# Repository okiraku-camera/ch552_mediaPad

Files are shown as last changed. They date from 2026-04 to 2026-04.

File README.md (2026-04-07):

# CH552 MediaPad

English version: [README_en.md](README_en.md)

CH552G マイクロコントローラを使ったUSB HID マクロパッド（2x4キー + エンコーダ搭載）です。WebHID を使ってキーマップをリアルタイムで設定・変更できます。

## フォルダ構成

- **`pcb/`**: KiCAD 8 による基板設計（回路図、PCB）
- **`plates/`**: レーザーカット用アクリルプレート設計
- **`mediaPad/`**: Arduino ファームウェア（CH552G 向け）
- **`html/`**: WebHID 設定用ブラウザアプリ（HTML/CSS/JavaScript）
- **`LICENSE`**: プロジェクトライセンス

## ハードウェア

- **マイコン**: CH552G
- **キー**: 8キー（2x4 レイアウト）
- **エンコーダ**: 1個
- **トッププレート**: 5mm アクリル（透明）
- **ミドルプレート**: 5mm アクリル（マット透明）
- **ボトムプレート**: 2mm アクリル（透明）
- **USB**: USB Type-C コネクタ

詳細は [pcb/README.md](pcb/README.md)・[plates/README.md](plates/README.md) をご覧ください。

## ソフトウェア

### ファームウェア (mediaPad/)
CH552G 向けの Arduino スケッチ。USB HID キーボード・メディア操作・エンコーダ入力に対応しています。

### Web アプリ (html/)
ブラウザから **WebHID** 経由でデバイスと通信し、キーマップの読み書きや設定変更ができるアプリケーションです。(ch552_mediaPad.html)

## ライセンス

このプロジェクトはハードウェアとソフトウェアから構成されています。

Copyright (c) Takeshi Higasa, okiraku-camera.tokyo

詳細は [LICENSE](./LICENSE) をご覧ください。

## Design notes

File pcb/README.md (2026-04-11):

# PCB (ch552_mediaPad)

このディレクトリには、CH552 MediaPad の KiCad 設計データ（回路図・基板レイアウト）が含まれています。

## 使用ツール

- KiCad 8.0

## 含まれる主なファイル

- `ch552_mediaPad.kicad_sch` : 回路図
- `ch552_mediaPad.kicad_pcb` : PCB レイアウト
- `ch552_mediaPad.kicad_pro` : プロジェクト設定
- `local/` : この PCB のためのフットプリントライブラリ

### local/ ディレクトリの内容

- `Hole_M3_SmallPad.kicad_mod` : M3 取り付け穴
- `MX_PCB_1.25u.kicad_mod` : 1.25u キースイッチ用フットプリント
- `MX_Plate_hole.kicad_mod` : MX スイッチ用フットプリントと置き換えて、スイッチプレートを設計するためのフットプリント
- `SW_Cherry_MX_PCB_RE_1.25u.kicad_mod` : MX 1.25U とロータリーエンコーダー EC-12 を組み合わせたフットプリント
- `USB_C_Receptacle_304J-BCP16.kicad_mod` : USB Type-C コネクタ

## メモ

- 共同作業時は、編集対象（回路図/PCB）と合わせて関連設定ファイルの差分も確認してください。

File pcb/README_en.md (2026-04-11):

# PCB (ch552_mediaPad)

This directory contains KiCad design data (schematics and PCB layout) for CH552 MediaPad.

## Tool

- KiCad 8.0

## Main Files

- `ch552_mediaPad.kicad_sch` : Schematic
- `ch552_mediaPad.kicad_pcb` : PCB layout
- `ch552_mediaPad.kicad_pro` : Project settings
- `local/` : Footprint library for this PCB

### Contents of local/

- `Hole_M3_SmallPad.kicad_mod` : M3 mounting hole
- `MX_PCB_1.25u.kicad_mod` : Footprint for 1.25u MX switch
- `MX_Plate_hole.kicad_mod` : Footprint used to design a switch plate by replacing the MX switch footprint
- `SW_Cherry_MX_PCB_RE_1.25u.kicad_mod` : Combined footprint for MX 1.25U and rotary encoder EC-12
- `USB_C_Receptacle_304J-BCP16.kicad_mod` : USB Type-C connector

## Notes

- When collaborating, check diffs in related project setting files along with schematic/PCB edits.

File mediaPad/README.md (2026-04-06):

# mediaPad firmware

English version is here: [README_en.md](README_en.md)

このディレクトリには、mediaPad ファームウェア（Arduino スケッチ）が入っています。

## 概要

mediaPad は、CH552G を使った **プログラマブルなメディアパッド/マクロパッド** です。  
キースキャン、ロータリーエンコーダ入力、USB HID 送信、キーマップ/マクロの永続保存を行い、WebHID ベースの WebUI から設定を変更できます。

このファームウェアの対象ハードウェアは **ch552_mediaPad** です。

## 主な機能

- **8 キー + ロータリーエンコーダ入力**: 2x4 のキー入力とエンコーダ回転を処理
- **2 レイヤーキーマップ**: EEPROM 上の 2 層キーマップを切り替えて利用
- **エンコーダ割り当て**: レイヤーごとに CW / CCW のキーコードを設定可能
- **マクロ機能**: 最大 6 個のマクロを保存し、割り当てキーから順次送信
- **WebUI 設定**: WebHID 経由でキーマップ、エンコーダ、マクロをブラウザから編集可能
- **永続ストレージ**: 設定は NVM（内蔵 EEPROM）に保存

## ソフトウェア構成

### ハードウェア層
| ファイル | 役割 |
|---|---|
| `mediaPad.ino` | メインスケッチ。入力スキャン、キー送信、レイヤー/マクロ制御 |
| `r_encoder.c/.h` | ロータリーエンコーダ入力処理 |
| `serial_led.c/.h` | LED 表示制御 |

### レイヤー・キーマップ管理
| ファイル | 役割 |
|---|---|
| `nvm_keymap.c/.h` | EEPROM へのキーマップ/マクロ保存処理 |
| `hardware_config.h` | キー数、レイヤー数、EEPROM マップなどの定数定義 |

### USB HID 通信
| ファイル | 役割 |
|---|---|
| `USB_hid_composite.c/.h` | USB HID 複合デバイス実装 |
| `hid_raw_request.c` | WebHID 設定要求（読み書きコマンド）処理 |

### PC側 Web アプリケーション
| ファイル | 役割 |
|---|---|
| `html/ch552_mediaPad.html` | Web アプリケーション画面 |
| `html/ch552_mediaPad.js` | WebHID 通信と UI ロジック |
| `html/style.css` | スタイル定義 |

## 動作モード

### レイヤー切り替え
- 2 レイヤーのキーマップを持ちます
- SW7 は固定 Fn キーとして扱われ、通常のキー割り当て変更対象ではありません
- Fn 操作により現在レイヤーを切り替えます

### エンコーダ動作
- ロータリーエンコーダ 1 個を搭載した構成です
- レイヤーごとに CW / CCW の 2 方向へ別々のキーコードを割り当てられます
- 既定ではメディア操作やスクロール系コードを割り当てる運用を想定しています

### マクロ動作
- マクロキー押下で登録済みマクロを順次送信します
- 実行中に別のキー入力があると、送信中マクロは停止します
- 遅延コードと繰返し制御コードを含むマクロを実行できます

## 使い方

### クイックスタート
1. ブラウザで `html/ch552_mediaPad.html` を開きます。
2. 「キーボードに接続」を押してデバイスを選択します。
3. 必要に応じてキーマップ、エンコーダ割り当て、マクロを編集します。
4. 「キーマップを書き込む」「マクロを書き込む」でデバイスへ保存します。

### WebUI の詳細手順

WebUI の操作手順は、以下の分離ドキュメントにまとめています。

- 日本語: `html/README.md`
- English: `html/README_en.md`

## ビルド方法

このファームウェアのビルドには、以下のソフトウェアが必要です。

- Visual Studio Code + vscode-arduino 拡張
- arduino-cli
- CH55xDuino
- Arduino libraries 配下の `ch552_keyPad_Library` が必須。

### arduino.json によるデバイス切り分け

本プロジェクトでは、デバイスごとのビルド依存設定を各スケッチディレクトリの `.vscode/arduino.json` で分離しています。

- `macro_numpad/.vscode/arduino.json`:
	- `sketch`: `macro_numpad.ino`
	- `buildPreferences`: `-DBOARD_NAME=CH552_MACRO_NUMPAD -I../common`
- `mediaPad/.vscode/arduino.json`:
	- `sketch`: `mediaPad.ino`
	- `buildPreferences`: `-DBOARD_NAME=CH552_MEDIAPAD -I../common`

この構成により、`software/common` の共通モジュールを再利用しながら、ターゲットごとのハードウェア依存データをボード名を使ったマクロで切り分けています。`.vscode/arduino.json` は以下のようになっています。

```json
{
    "configuration": "clock=16internal,usb_settings=user148,upload_method=usb,bootloader_pin=p36",
    "board": "CH55xDuino:mcs51:ch552",
    "sketch": "mediaPad\\mediaPad.ino",
    "output": "./built",
    "port": "COM1",
    "buildPreferences": [
        ["compiler.cpp.extra_flags","-DCH552_MEDIAPAD"],
        ["compiler.c.extra_flags","-DCH552_MEDIAPAD"]
    ]
}
```

VS Code の vscode-arduino 拡張は内部で arduino-cli を利用し、これらの設定を使ってビルドします。

### ボード設定

ボード設定メニューで以下を選択してください。

- USB Settings: `USER CODE w/ 148B USB ram`

この設定は HID エンドポイントに必要な USB RAM を確保するために必要です。

## 技術詳細

### NVM（128バイト）の使用方法
- **0～1バイト**: キーマップ有効フラグ（`0xAA55`）
- **2～33バイト**: 2 レイヤー分のキーキーマップ（8 キー x 2 バイト x 2 レイヤー）
- **34～41バイト**: ロータリーエンコーダ割り当て（1 個 x CW/CCW x 2 レイヤー x 2 バイト）
- **42～126バイト**: マクロ文字列データ
- **127バイト**: マクロ領域終端（予約）

### マクロ機能
- **最大 6 マクロ** を登録可能
- **マクロ領域は 85 バイト** です
- 1 マクロストリングの UI 上限は **50 バイト** です
- 各マクロはゼロ終端の連続列として管理されます

### マクロ制御コード
- **遅延コード**:
	- `0xDC` = 100ms
	- `0xDD` = 500ms
	- `0xDE` = 1sec
- **繰返しコード**:
	- `0xDA` = SEGSTART
	- `0xDB` = GOTO_SEG

### 繰返し動作の仕様
- `GOTO_SEG` は、そのマクロ内で最初に見つかった `SEGSTART` 位置へ戻ります
- `SEGSTART` が存在しない場合は、マクロ先頭へ戻ります

## トラブルシューティング

### デバイスが接続できない
- ブラウザが WebHID をサポートしているか確認してください（Chrome、Edge 推奨）
- デバイスが WebHID 通信可能な状態で接続されているか確認してください
- ブラウザの USB アクセス権限を確認してください

### キーマップやエンコーダ設定が反映されない
- 「キーマップを書き込む」で変更を保存しているか確認してください
- Pending 状態の変更は、読み出しだけでは反映されません
- 一度「キーマップを読み出す」を実行してから再編集すると切り分けしやすくなります

### マクロが期待どおり動作しない
- マクロスロットと割り当て先キーが正しいか確認してください
- マクロ容量上限を超えていないか確認してください
- 遅延コードや繰返しコードを意図どおりに配置しているか確認してください

## 補足

- Web 設定ツールは [html/ch552_mediaPad.html](html/ch552_mediaPad.html) を使用します
- 接続時にデバイスのバージョン番号を確認しています（想定値: `0x1234`）
- ブートローダー開始後はデバイスが一時的に切断されることがあります

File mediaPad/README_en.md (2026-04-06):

# mediaPad firmware

Japanese version is here: [README.md](README.md)

This directory contains the mediaPad firmware (Arduino sketch) for CH552G.

## Overview

mediaPad is a **programmable media pad / macro pad** based on CH552G.  
It handles key scanning, rotary encoder input, USB HID transmission, and persistent storage of keymaps/macros, and its settings can be updated from a WebHID-based Web UI.

The target hardware for this firmware is **ch552_mediaPad**.

## Main Features

- **8 keys + rotary encoder input**: handles a 2x4 key matrix and encoder rotation
- **2-layer keymap**: uses a two-layer keymap stored in EEPROM
- **Encoder assignment**: CW / CCW keycodes can be configured per layer
- **Macro support**: stores up to 6 macros and sends them from assigned keys
- **WebUI configuration**: keymaps, encoder assignments, and macros can be edited from the browser via WebHID
- **Persistent storage**: settings are stored in NVM (built-in EEPROM)

## Software Structure

### Hardware Layer
| File | Role |
|---|---|
| `mediaPad.ino` | Main sketch: input scan, key send, layer/macro control |
| `r_encoder.c/.h` | Rotary encoder input processing |
| `serial_led.c/.h` | LED control |

### Layer and Keymap Management
| File | Role |
|---|---|
| `nvm_keymap.c/.h` | EEPROM keymap/macro storage processing |
| `hardware_config.h` | Constants such as key count, layer count, and EEPROM layout |

### USB HID Communication
| File | Role |
|---|---|
| `USB_hid_composite.c/.h` | USB HID composite device implementation |
| `hid_raw_request.c` | WebHID configuration request handling (read/write commands) |

### PC-side Web Application
| File | Role |
|---|---|
| `html/ch552_mediaPad.html` | Web application UI |
| `html/ch552_mediaPad.js` | WebHID communication and UI logic |
| `html/style.css` | Styling |

## Operation Modes

### Layer Switching
- The firmware uses a 2-layer keymap
- SW7 is treated as a fixed Fn key and is not a normal remappable key
- Fn operation switches the current layer

### Encoder Behavior
- The device uses one rotary encoder
- Separate keycodes can be assigned to CW and CCW for each layer
- The default use case assumes media-control or scroll-related keycodes

### Macro Behavior
- Pressing a macro key sends the registered macro sequence
- If another key is pressed during macro execution, the running macro stops
- Macros can include delay codes and loop-control codes

## Usage

### Quick Start
1. Open `html/ch552_mediaPad.html` in a browser.
2. Click "Connect to Keyboard" and select the device.
3. Edit the keymap, encoder assignments, and macros as needed.
4. Save changes to the device with "Write keymap" and "Write macro".

### Detailed WebUI Guide

Detailed WebUI steps are documented in the following files.

- Japanese: `html/README.md`
- English: `html/README_en.md`

## Build

The following software is required to build this firmware.

- Visual Studio Code + vscode-arduino extension
- arduino-cli
- CH55xDuino
- `ch552_keyPad_Library` under Arduino libraries is required.

### Device Split by arduino.json

This project separates device-specific build settings using `.vscode/arduino.json` under each sketch directory.

- `macro_numpad/.vscode/arduino.json`:
	- `sketch`: `macro_numpad.ino`
	- `buildPreferences`: `-DBOARD_NAME=CH552_MACRO_NUMPAD -I../common`
- `mediaPad/.vscode/arduino.json`:
	- `sketch`: `mediaPad.ino`
	- `buildPreferences`: `-DBOARD_NAME=CH552_MEDIAPAD -I../common`

With this setup, shared modules in `software/common` are reused while hardware-dependent data is separated by the `BOARD_NAME` macro. See the `.vscode/arduino.json` files in the source tree for the concrete settings.

The `.vscode/arduino.json` file looks like this:

```json
{
	"configuration": "clock=16internal,usb_settings=user148,upload_method=usb,bootloader_pin=p36",
	"board": "CH55xDuino:mcs51:ch552",
	"sketch": "mediaPad\\mediaPad.ino",
	"output": "./built",
	"port": "COM1",
	"buildPreferences": [
		["compiler.cpp.extra_flags","-DCH552_MEDIAPAD"],
		["compiler.c.extra_flags","-DCH552_MEDIAPAD"]
	]
}
```

The vscode-arduino extension uses arduino-cli internally and builds with these settings.

### Board Settings

Select the following option in board settings.

- USB Settings: `USER CODE w/ 148B USB ram`

This setting is required to allocate the USB RAM needed for HID endpoints.

## Technical Details

### NVM layout (128 bytes)
- **Bytes 0-1**: keymap valid flag (`0xAA55`)
- **Bytes 2-33**: key keymap for 2 layers (8 keys x 2 bytes x 2 layers)
- **Bytes 34-41**: rotary encoder assignments (1 encoder x CW/CCW x 2 layers x 2 bytes)
- **Bytes 42-126**: macro string data
- **Byte 127**: macro area terminator (reserved)

### Macro Features
- Supports **up to 6 macros**
- **Macro storage size is 85 bytes**
- UI limit for one macro string is **50 bytes**
- Each macro is stored as a zero-terminated continuous sequence

### Macro Control Codes
- **Delay codes**:
	- `0xDC` = 100 ms
	- `0xDD` = 500 ms
	- `0xDE` = 1 sec
- **Loop control codes**:
	- `0xDA` = SEGSTART
	- `0xDB` = GOTO_SEG

### Loop Behavior
- `GOTO_SEG` jumps back to the first `SEGSTART` found in the current macro
- If no `SEGSTART` exists, it jumps back to the beginning of the macro

## Troubleshooting

### Cannot connect to the device
- Check whether your browser supports WebHID (Chrome and Edge recommended)
- Check whether the device is connected in a WebHID-capable state
- Check USB access permissions in the browser

### Keymap or encoder settings are not applied
- Make sure you saved changes with "Write keymap"
- Pending changes are not applied by read operations alone
- Try running "Read keymap" once and then editing again to help isolate the issue

### Macros do not behave as expected
- Check whether the macro slot and assigned key are correct
- Check whether the macro storage limit has been exceeded
- Check whether delay codes and loop-control codes are arranged as intended

## Notes

- Use `html/ch552_mediaPad.html` as the Web configuration tool
- The device version is checked on connection (expected value: `0x1234`)
- Starting the bootloader may temporarily disconnect the device

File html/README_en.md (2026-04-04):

# MediaPad Web Config

This directory contains the Web configuration app for CH552 MediaPad.  
Using WebHID in the browser, you can read and write the device keymap, encoder assignments, and macros.

## Files

- `ch552_mediaPad.html`: Main UI page
- `ch552_mediaPad.js`: WebHID communication and UI logic
- `style.css`: Stylesheet

## Features

- Device connection via WebHID
- Keymap read/write (2 layers)
- Rotary encoder assignment read/write (CW / CCW)
- Macro read/write
- Macro editor dialog (add, delete, clear, storage usage display)
- Reset keymap to defaults
- Start bootloader
- Read NVM dump and macro ptrs
- Log view / clear

## Requirements

- WebHID-compatible browser (Chrome / Edge, etc.)
- MediaPad firmware connected and running with WebHID support
- Target device must match:
  - Vendor ID: `0x1209`
  - Usage Page: `0xFF82`
  - Usage: `0x51`

## Usage

1. Open `ch552_mediaPad.html` in your browser.
2. Click "キーボードに接続" (Connect keyboard), then select the target device.
3. After connection, use the controls as needed:
   - "キーマップを読み出す": Read current key/encoder assignments
   - Click a key to change assignment (shown as pending on the UI)
   - "キーマップを書き込む": Apply pending keymap changes to the device
   - "マクロを編集する": Open macro editor and modify macro content
   - "マクロを書き込む": Save macro edits to EEPROM
4. If needed, use "デフォルトにリセット" (reset to defaults) or "ブートローダー開始" (start bootloader).

## Notes

- SW7 is treated as a fixed Fn key (`0xBC`) and cannot be changed in normal operation.
- Macro area size is 85 bytes (managed as a contiguous macro sequence).
- The per-macro-string spec limit is 50 bytes (validated on the UI side).
- Macro editor "Delay/Repeat" section:
  - Delay: `0xDC` (100ms), `0xDD` (500ms), `0xDE` (1sec)
  - Repeat: `0xDA` (SEGSTART), `0xDB` (GOTO_SEG)
- Firmware repeat behavior:
  - `GOTO_SEG` returns to the first `SEGSTART` found in the current macro string.
  - If no `SEGSTART` is found, execution returns to the start of the current macro string.
- If unsaved macro edits exist, reading macros again prompts for confirmation.
- On device disconnect, the app resets UI state and pending command state.

## Additional Info

- On connect, the app validates the firmware version (expected: `0x1234`).
- After starting the bootloader, the device may disconnect.

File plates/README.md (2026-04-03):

# レーザーカット アクリルプレートと PCB アセンブリ

English version is here: [README_en.md](README_en.md)

このディレクトリは、アクリル板を使った3種類のプレートの寸法図(*.pdf)と、発注用のカットアウト図 (*.dxf)を含んでいます。

このダイアグラムは、PCB とアクリルプレートを含むマルチレイヤー構造のアセンブリ構成を示しています。

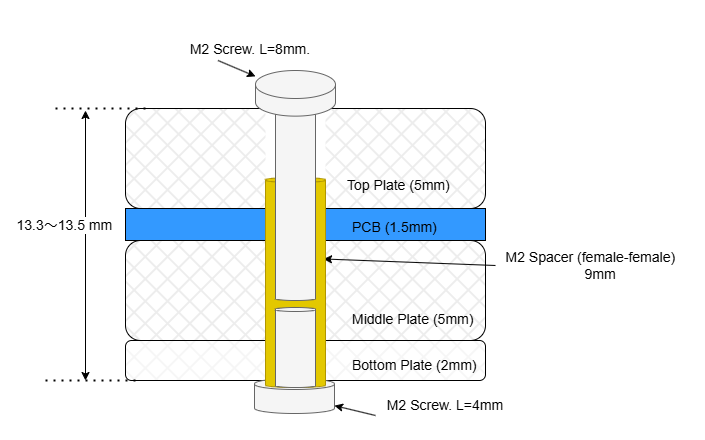
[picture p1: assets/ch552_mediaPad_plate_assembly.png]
structure


* プレートと PCB
  * トッププレート (5mm): アセンブリの最上層は 5mm 厚の透明アクリルプレートです。
  * PCB (1.5mm): トッププレートの下に位置するのは 1.5mm 厚の PCB です。
  * ミドルプレート (5mm): PCB の下に位置するのは 5mm 厚のマット透明アクリルプレートです。
  * ボトムプレート (2mm): アセンブリの最下層は 2mm 厚の透明アクリルプレートです。

* 固定部品
  * M2 スクリュー (8mm): アセンブリの上部を固定するために使用します。
  * M2 スクリュー (4mm): アセンブリの下部を固定するために使用します。
  * M2 スペーサー (オス-メス, 9mm): 9mm 長の M2 スペーサーが 2 本のスクリュー間に配置されます（下部から）。

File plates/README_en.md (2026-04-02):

# Laser-cut acrylic plates and PCB assembly.

This directory contains dimensions (*.pdf) for three acrylic plates and cutout drawings (*.dxf) for manufacturing orders.

structure

This diagram shows the assembly structure of a multi-layered setup including a PCB and acrylic plates. 

* Plates and PCB
  * Top Plate (5mm): The top layer of the assembly is a 5mm thick transparent acrylic plate.
  * PCB (1.5mm): Below the top plate is the PCB, which is a 1.5mm thick.
  * Middle Plate (5mm): Positioned beneath the PCB is another 5mm thick matte-transparent acrylic plate.
  * Bottom Plate (2mm): The bottom layer of the assembly is a 2mm thick transparent acrylic plate.

* Fastening Components
  * An 8mm M2 screw is used to secure the top of the assembly.
  * A 4mm M2 screw is used to secure the bottom of the assembly. 
  * M2 Spacer (male-female, 9mm): A 9mm long M2 spacer is placed between 2 screws, from the bottom.

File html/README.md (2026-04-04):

# MediaPad Web Config

English version: [README_en.md](README_en.md)

このディレクトリには、CH552 MediaPad の設定用 Web アプリが含まれています。  
ブラウザの WebHID を使って、デバイスのキーマップ・エンコーダ設定・マクロを読み書きできます。

## ファイル構成

- `ch552_mediaPad.html`: 画面本体
- `ch552_mediaPad.js`: WebHID 通信と UI ロジック
- `style.css`: 画面スタイル

## 主な機能

- デバイス接続（WebHID）
- キーマップ読み出し / 書き込み（2レイヤー）
- ロータリーエンコーダ（CW / CCW）割り当ての読み出し / 書き込み
- マクロ読み出し / 書き込み、マクロキーは6つまで。
- マクロ編集ダイアログ（追加、削除、クリア、容量表示）
- キーマップをデフォルトにリセット
- ブートローダー開始
- NVM ダンプ表示、macro ptrs 読み出し
- ログ表示 / クリア

## 動作要件

- WebHID 対応ブラウザ（Chrome / Edge など）
- MediaPad ファームウェアが WebHID 通信可能な状態で接続されていること
- 接続対象は以下に一致するデバイス
  - Vendor ID: `0x1209`
  - Usage Page: `0xFF82`
  - Usage: `0x51`

## 使い方

1. `ch552_mediaPad.html` をブラウザで開きます。
2. 「キーボードに接続」を押し、対象デバイスを選択します。
3. 接続後、必要に応じて次を実行します。
   - 「キーマップを読み出す」: 現在のキー / エンコーダ割り当てを取得
   - キーをクリックして割り当て変更（画面上は Pending 状態）
   - 「キーマップを書き込む」: Pending 変更をデバイスへ反映
   - 「マクロを編集する」: マクロ編集ダイアログを開いて内容を変更
   - 「マクロを書き込む」: 編集内容を EEPROM へ保存
4. 必要に応じて「デフォルトにリセット」や「ブートローダー開始」を使います。

## 仕様メモ

- SW7 は固定 Fn キー（`0xBC`）として扱われ、通常操作では変更できません。
- マクロ領域は 85 バイトです（連続したマクロ列として管理）。
- 1マクロストリングの仕様上限は 50 バイトです（UI 側でチェック）。
- マクロ編集ダイアログの「遅延・繰返し」セクション:
  - 遅延: `0xDC` (100ms), `0xDD` (500ms), `0xDE` (1sec)
  - 繰返し: `0xDA` (SEGSTART), `0xDB` (GOTO_SEG)
- ファームウェア実行時の繰返し動作:
  - `GOTO_SEG` は、現在のマクロ内で最初に検出した `SEGSTART` 位置へ戻ります。
  - `SEGSTART` 未検出の場合はマクロ先頭へ戻ります。
- 未保存のマクロ編集がある場合、マクロ再読み出し時に確認が入ります。
- デバイス切断時は UI 状態と待機中コマンド状態をリセットします。

## 補足

- 接続時にデバイスのバージョン番号を確認しています（想定値: `0x1234`）。
- ブートローダー開始後はデバイスが切断されることがあります。

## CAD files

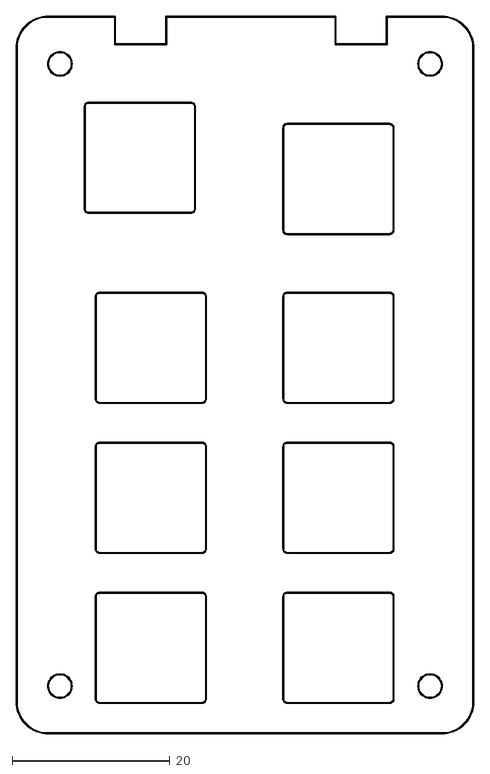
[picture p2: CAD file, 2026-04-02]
plates/ch552_macropad_2x4_top.dxf
58.1 x 91.1

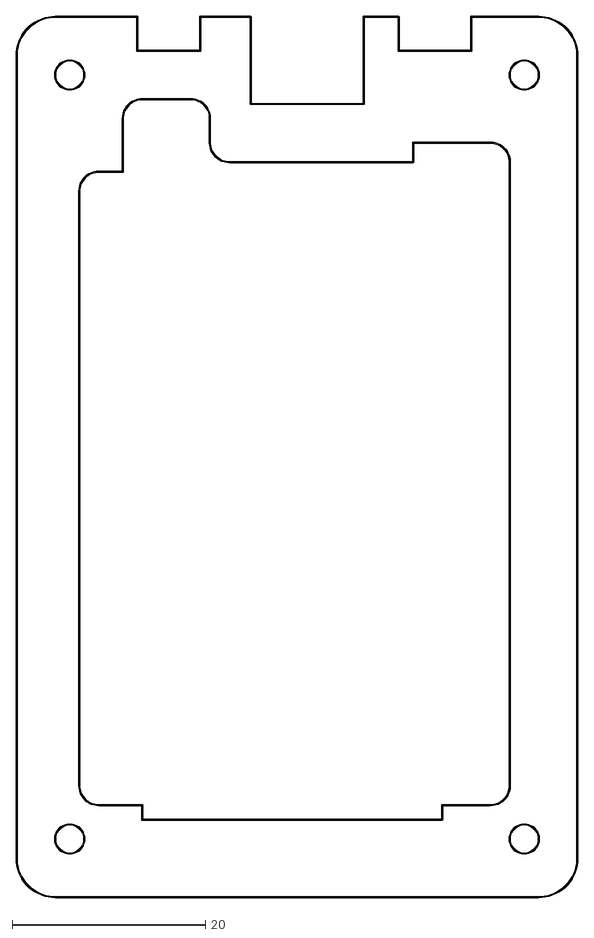
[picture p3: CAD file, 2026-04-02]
plates/ch552_macropad_2x4_middle.dxf
58.1 x 91.1

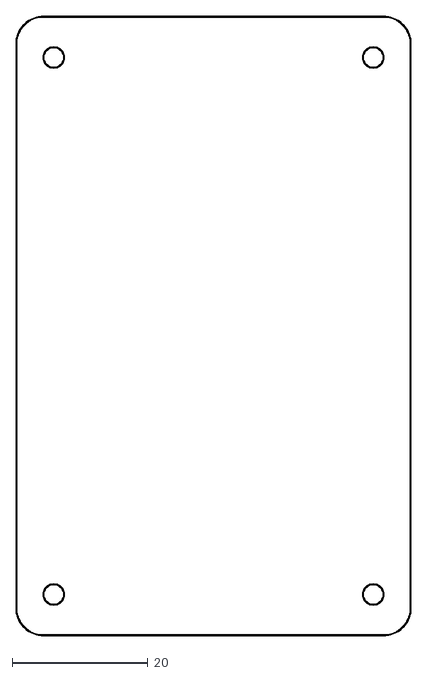
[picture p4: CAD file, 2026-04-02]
plates/ch552_macropad_2x4_bottom.dxf
58.1 x 91.1

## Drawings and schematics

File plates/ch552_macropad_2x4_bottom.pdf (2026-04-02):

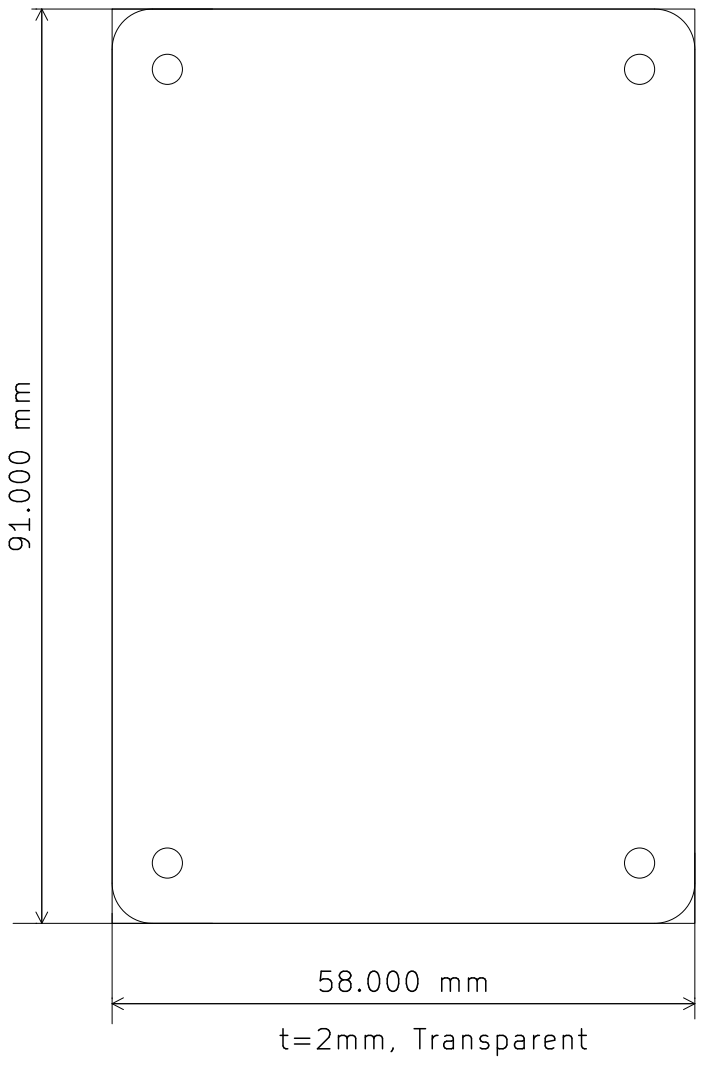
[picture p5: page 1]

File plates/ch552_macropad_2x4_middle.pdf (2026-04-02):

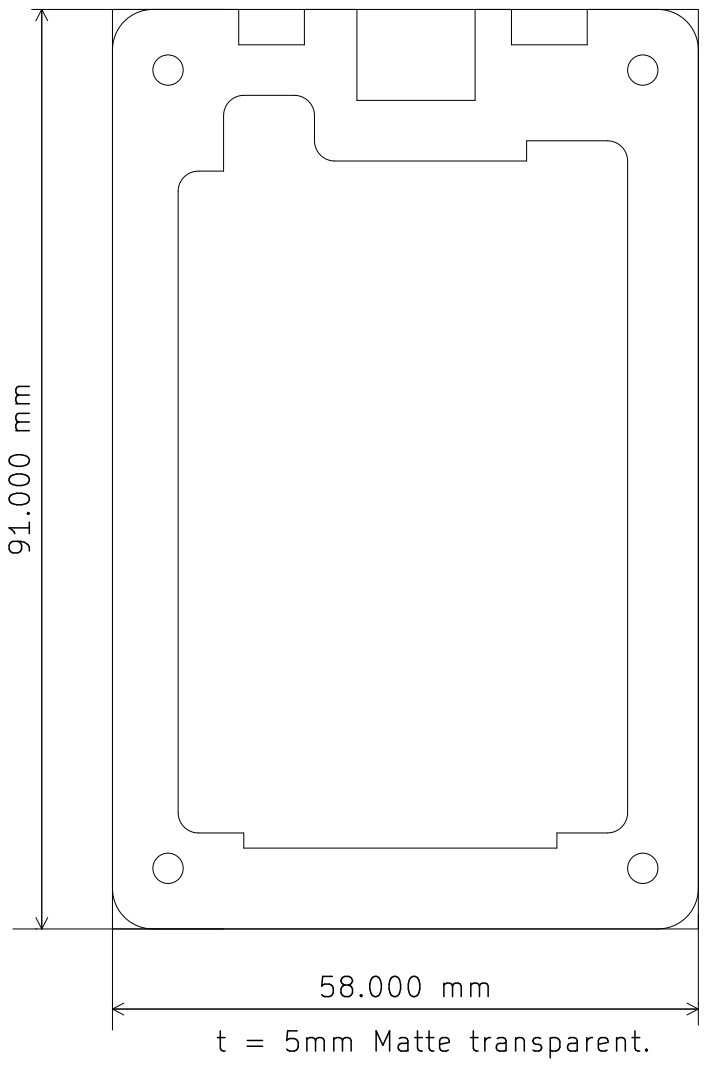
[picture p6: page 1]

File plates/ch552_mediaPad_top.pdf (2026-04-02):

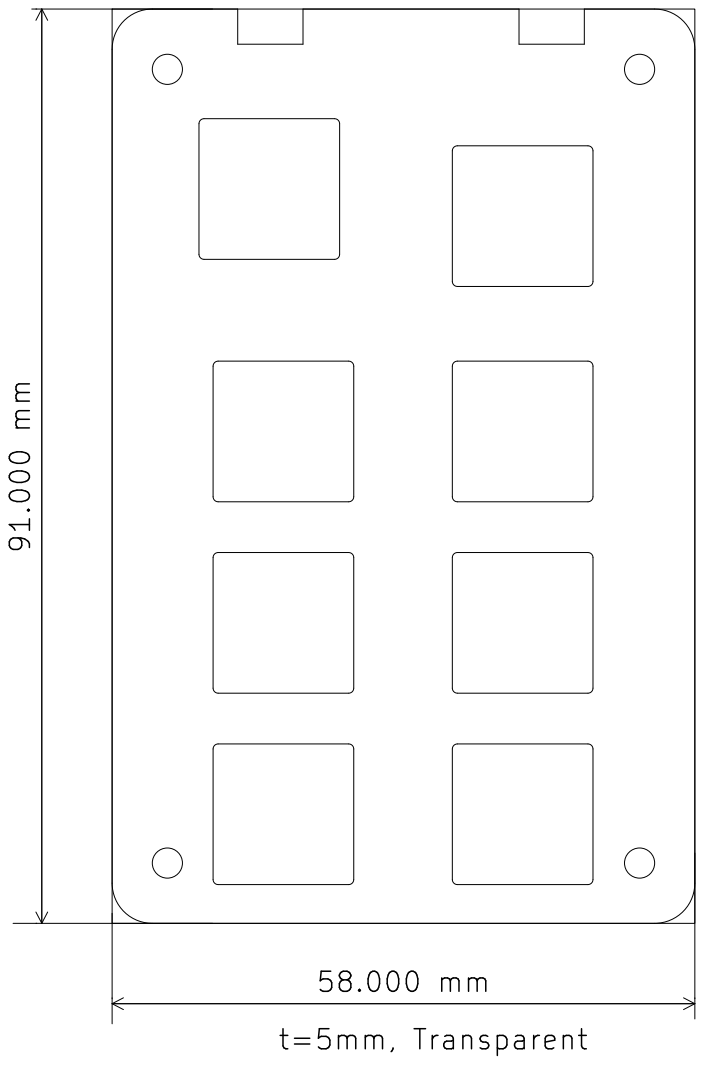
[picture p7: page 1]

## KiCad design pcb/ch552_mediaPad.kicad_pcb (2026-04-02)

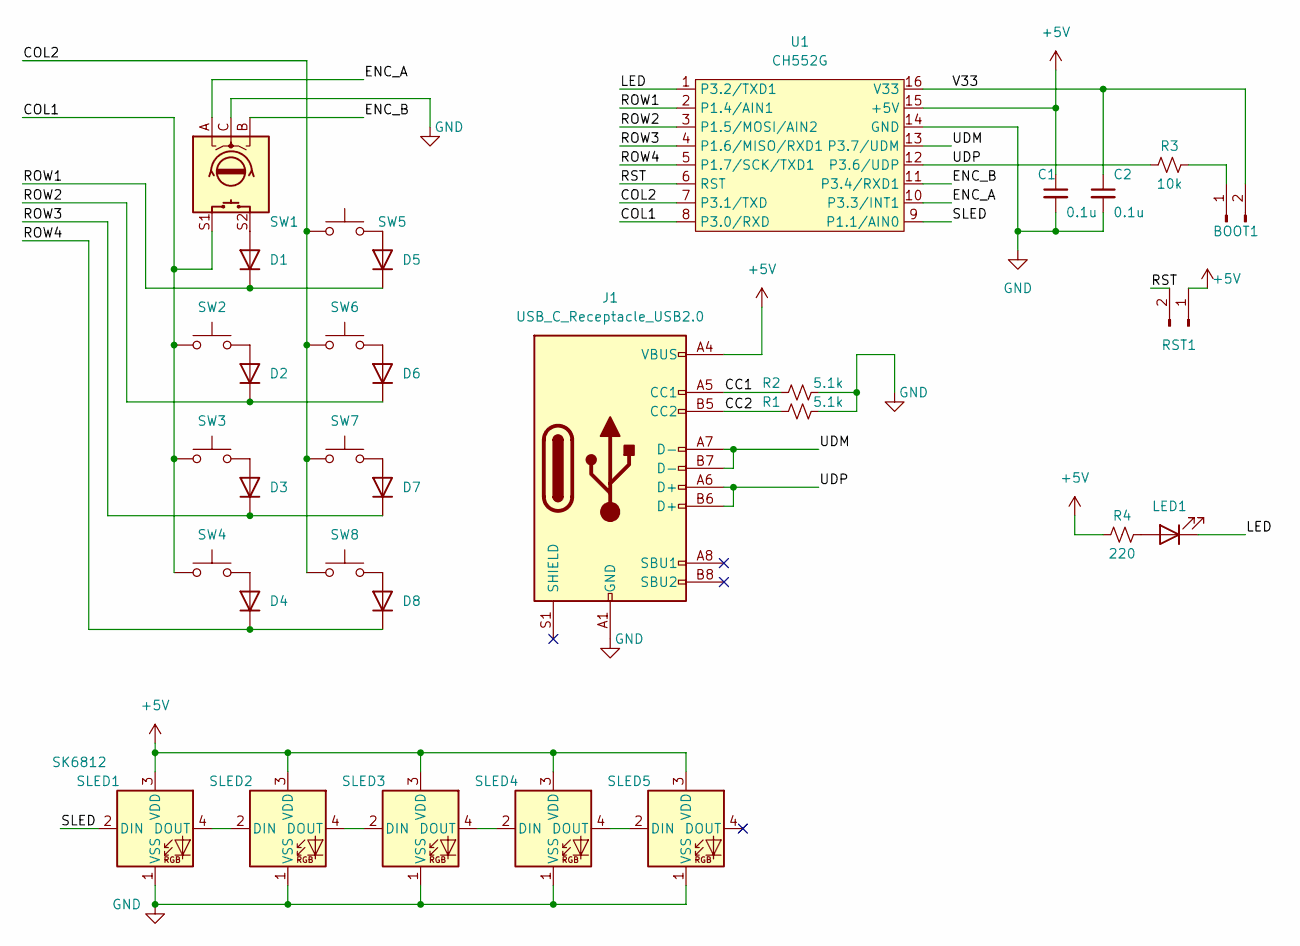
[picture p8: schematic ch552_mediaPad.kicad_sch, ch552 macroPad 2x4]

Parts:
BOOT1: Conn_01x02_Male; PinHeader_1x02_P2.54mm_Vertical
C1, C2: 0.1u; C_0603_1608Metric
D1, D2, D3, D4, D5, D6, D7, D8: 1N4148W; D_SOD-123
J1: USB_C_Receptacle_USB2.0; USB_C_Receptacle_304J-BCP16
LED1: LED; LED_1206_3216Metric_Pad1.42x1.75mm_HandSolder
R1, R2: 5.1k; R_0402_1005Metric
R3: 10k; R_0402_1005Metric
R4: 220; R_0402_1005Metric
RST1: Conn_01x02_Male; PinHeader_1x02_P2.54mm_Vertical
SLED1, SLED2, SLED3, SLED4, SLED5: SK6812; LED_SK6812_PLCC4_5.0x5.0mm_P3.2mm
SW1: RotaryEncoder_Switch; SW_Cherry_MX_PCB_RE_1.25u
SW2, SW3, SW4, SW5, SW6, SW7, SW8: SW_Push; MX_PCB_1.25u
U1: CH552G; SOP-16_3.9x9.9mm_P1.27mm

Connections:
+5V: C1.1, J1.A4 (VBUS), J1.A9 (VBUS), J1.B4 (VBUS), J1.B9 (VBUS), R4.1, RST1.1, SLED1.3 (VDD), SLED2.3 (VDD), SLED3.3 (VDD), SLED4.3 (VDD), SLED5.3 (VDD), U1.15 (+5V)
/CC1: J1.A5 (CC1), R2.1
/CC2: J1.B5 (CC2), R1.1
/COL1: SW1.S1, SW2.1, SW3.1, SW4.1, U1.8 (P3.0/RXD)
/COL2: SW5.1, SW6.1, SW7.1, SW8.1, U1.7 (P3.1/TXD)
/ENC_A: SW1.A, U1.10 (P3.3/INT1)
/ENC_B: SW1.B, U1.11 (P3.4/RXD1)
/LED: LED1.1 (K), U1.1 (P3.2/TXD1)
/ROW1: D1.1 (K), D5.1 (K), U1.2 (P1.4/AIN1)
/ROW2: D2.1 (K), D6.1 (K), U1.3 (P1.5/MOSI/AIN2)
/ROW3: D3.1 (K), D7.1 (K), U1.4 (P1.6/MISO/RXD1)
/ROW4: D4.1 (K), D8.1 (K), U1.5 (P1.7/SCK/TXD1)
/RST: RST1.2, U1.6 (RST)
/SLED: SLED1.2 (DIN), U1.9 (P1.1/AIN0)
/UDM: J1.A7 (D-), J1.B7 (D-), U1.13 (P3.7/UDM)
/UDP: J1.A6 (D+), J1.B6 (D+), R3.1, U1.12 (P3.6/UDP)
/V33: BOOT1.2, C2.1, U1.16 (V33)
GND: C1.2, C2.2, J1.A1 (GND), J1.A12 (GND), J1.B1 (GND), J1.B12 (GND), R1.2, R2.2, SLED1.1 (VSS), SLED2.1 (VSS), SLED3.1 (VSS), SLED4.1 (VSS), SLED5.1 (VSS), SW1.C, U1.14 (GND)
unnamed: BOOT1.1, R3.2
unnamed: D1.2 (A), SW1.S2
unnamed: D2.2 (A), SW2.2
unnamed: D3.2 (A), SW3.2
unnamed: D4.2 (A), SW4.2
unnamed: D5.2 (A), SW5.2
unnamed: D6.2 (A), SW6.2
unnamed: D7.2 (A), SW7.2
unnamed: D8.2 (A), SW8.2
unnamed: LED1.2 (A), R4.2
unnamed: SLED1.4 (DOUT), SLED2.2 (DIN)
unnamed: SLED2.4 (DOUT), SLED3.2 (DIN)
unnamed: SLED3.4 (DOUT), SLED4.2 (DIN)
unnamed: SLED4.4 (DOUT), SLED5.2 (DIN)

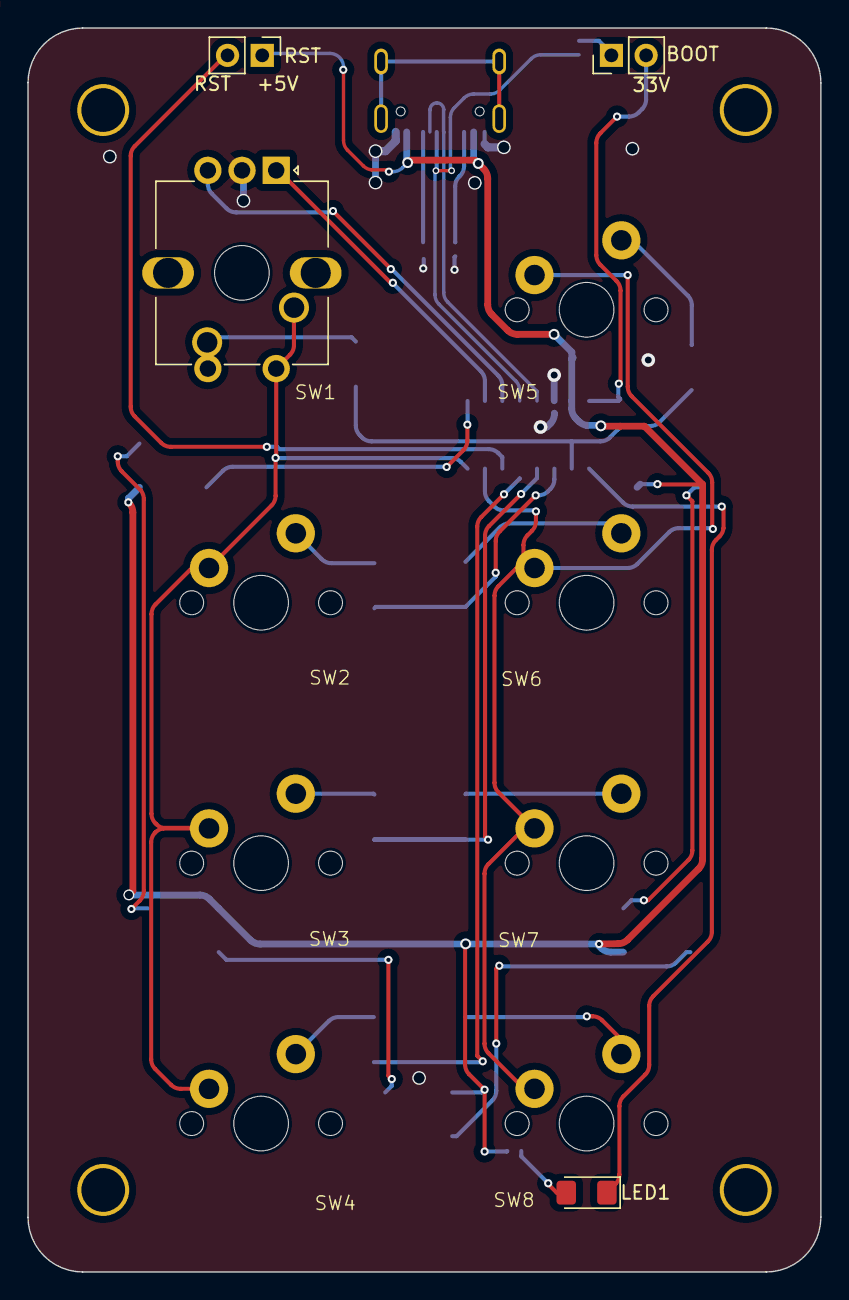
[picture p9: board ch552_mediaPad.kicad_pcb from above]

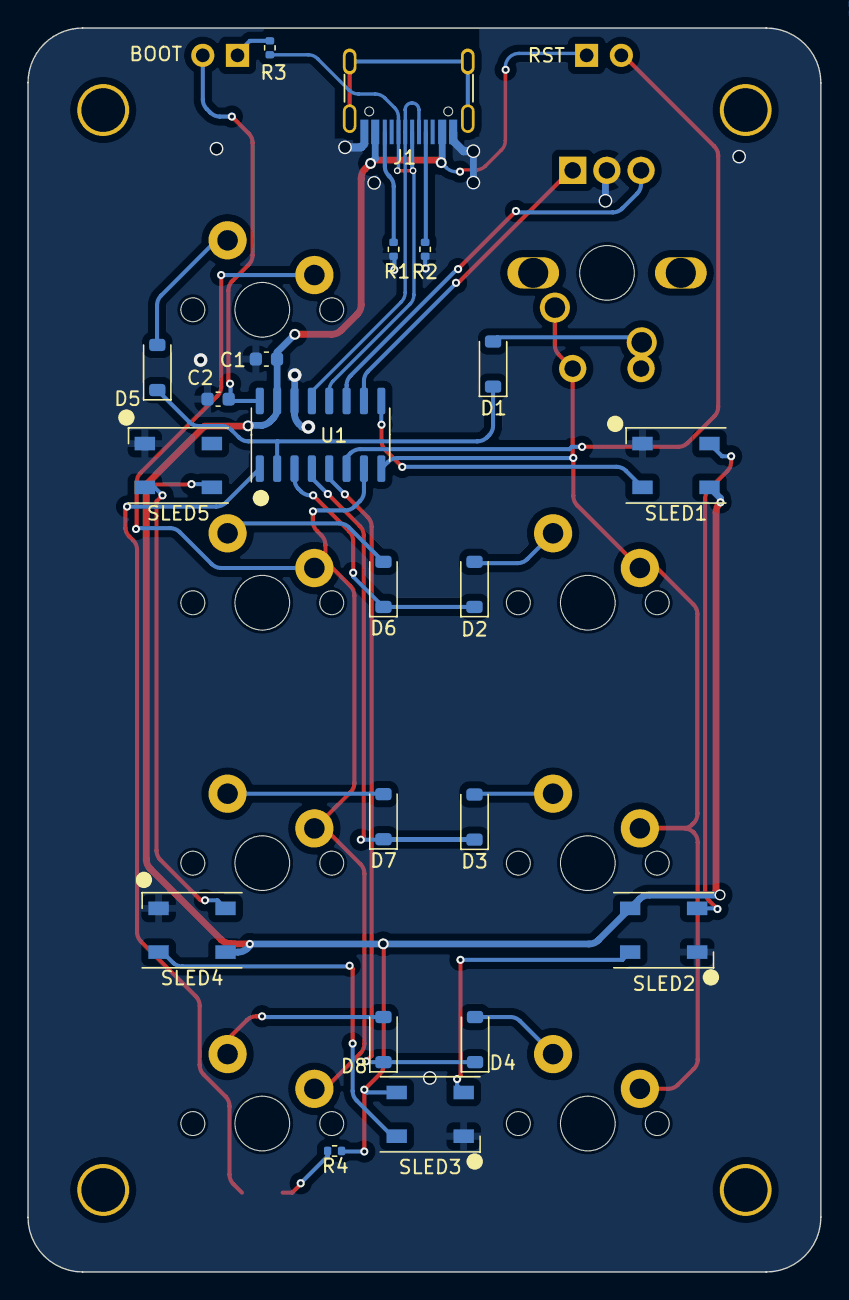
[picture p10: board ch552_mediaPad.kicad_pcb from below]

Board: 2 copper layers, 58.0 x 91.0 mm, 33 parts (21 on the bottom side), 32 nets.

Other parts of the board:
REF: Hole_M3_SmallPad

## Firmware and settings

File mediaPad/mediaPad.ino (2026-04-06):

/**
 * mediaPad.ino main sketch of mediapad program using ch552g.
 * Copyright (c)  Takeshi Higasa, okiraku-camera.tokyo
 * 
 * This software is released under the MIT License.
 * http://opensource.org/licenses/mit-license.php
 * 
 */

#include "USB_hid_composite.h"
#include "hid_keycode.h"
#include "ch552_watchdog.h"
#include "nvm_keymap.h"	
#include "serial_led.h"
#include "hardware_config.h"	// for hardware dependent constants.

#define numlock_led  11
const uint8_t cols[] = {30, 31};
const uint8_t rows[] = {14, 15, 16, 17};
const uint8_t row_masks[] = {0x10, 0x20, 0x40, 0x80};

#define KB_LED_PIN	32
#define KB_LED_OFF 	1	// high to off.
#define KB_LED_ON 	0

void led_off() {
	sled_off();
	digitalWrite(KB_LED_PIN, KB_LED_OFF);
}


// Initial layout .
// This layout is written to NVM on first boot and reset command. User can change the layout by writing to NVM.
const uint16_t intial_layout[NUM_KEYS] = {
	HID_KEYPAD_0,
	HID_KEYPAD_1,
	HID_KEYPAD_2,
	HID_KEYPAD_3,
	HID_KEYPAD_4,
	HID_KEYPAD_5,
	HID_KEYPAD_6,
	HID_KEYPAD_7
};

const uint16_t intial_re_layout[RE_COUNT * 2] = {
	FN_MEDIA_VOL_UP, 
	FN_MEDIA_VOL_DOWN,	// RE0 layer0, CW, CCW
	FN_MS_WH_UP,
	FN_MS_WH_DOWN		// RE0 layer1, CW, CCW
};

void build_initial_layout() {
	// build initial layout. this is used when nvm is not valid.
	for(int8_t i = 0; i < NUM_KEYS ; i++) {	
		uint16_t code = intial_layout[i];
		nvm_write_word(KEYMAP_START + (i << 1), code);				// レイヤー0はテンキー
		nvm_write_word(KEYMAP_START + NUM_KEYS * 2 + (i << 1), 0);	// レイヤー1はすべて0
	}
	for(int8_t i = 0; i < RE_COUNT * 2; i++) {	
		uint16_t code = intial_re_layout[i];
		nvm_write_word(RE_KEYMAP_START + (i << 1), code);				// レイヤー0
		code = intial_re_layout[i + 2];
		nvm_write_word(RE_KEYMAP_START + RE_COUNT * 4 + (i << 1), 0);	// レイヤー1
	}

}

int8_t current_layer = 0;	// 0 or 1. this is used for macropad layer switching.

void write_code_callback(uint8_t sw, uint8_t layer, uint16_t code) {
	sw;
	code;
	layer;
	// this is a callback function called when key code is written to NVM.
	// user can implement custom processing here when key code is updated, such as sending a notification to host, etc.
}


// called from USBhandler
void USBStartSuspend() {
	led_off();
}

uint8_t active_macro = 0;	// 0 means no active macro. 1～MACRO_KEY_COUNT means active macro index. this is set when macro key is pressed, and reset when macro code is sent.
uint8_t macro_index = 0;	// Index tracking the current position within the macro sequence referenced by activa_macro.
int8_t macro_delay_count = 0;	// Counter for tracking delay steps in macro execution, used when processing delay codes within a macro sequence.

typedef struct {
	uint16_t code;
	uint8_t pressed;
} queued_key_t;

#define KEY_SEND_QUEUE_BYTES 10
static uint8_t key_send_queue[KEY_SEND_QUEUE_BYTES];
static uint8_t key_send_queue_head = 0;
static uint8_t key_send_queue_tail = 0;
static uint8_t key_send_queue_used = 0;

static void key_send_queue_put_byte(uint8_t value) {
	key_send_queue[key_send_queue_tail] = value;
	key_send_queue_tail = (key_send_queue_tail + 1) % KEY_SEND_QUEUE_BYTES;
}

static uint8_t key_send_queue_get_byte() {
	uint8_t value = key_send_queue[key_send_queue_head];
	key_send_queue_head = (key_send_queue_head + 1) % KEY_SEND_QUEUE_BYTES;
	return value;
}

bool put_key_send_queue(uint16_t code, uint8_t pressed) {
	if (key_send_queue_used + sizeof(queued_key_t) > KEY_SEND_QUEUE_BYTES)
		return false;
	key_send_queue_put_byte((uint8_t)(code & 0xFF));
	key_send_queue_put_byte((uint8_t)((code >> 8) & 0xFF));
	key_send_queue_put_byte(pressed ? 1 : 0);
	key_send_queue_used += sizeof(queued_key_t);
	return true;
}

bool get_key_send_queue(queued_key_t* out) {
	if (!out)
		return false;
	if (key_send_queue_used < sizeof(queued_key_t))
		return false;
	uint8_t lo = key_send_queue_get_byte();
	uint8_t hi = key_send_queue_get_byte();
	out->code = (uint16_t)lo | ((uint16_t)hi << 8);
	out->pressed = key_send_queue_get_byte();
	key_send_queue_used -= sizeof(queued_key_t);
	return true;
}

static bool should_run_periodic(unsigned long* last_time, unsigned long interval_ms) {
	unsigned long now = millis();
	if (*last_time == 0) {
		*last_time = now;
		return false;
	}
	if ((unsigned long)(now - *last_time) < interval_ms)
		return false;
	*last_time = now;
	return true;
}

void process_send_key_queue() {
	static unsigned long last_time = 0;
	if (!should_run_periodic(&last_time, 10))
		return;

	queued_key_t item;
	if (get_key_send_queue(&item)) {
		send_key(item.code, item.pressed);
	}
}

void key_event(uint8_t switch_num, uint8_t state) {
	if (switch_num < 1 || switch_num > NUM_KEYS )
		return;

	if (active_macro) {
		if (state) {
			macro_index = 0;
			macro_delay_count = 0;
			active_macro = 0;
			kbd_releaseAll();
		}
		return;
	}	
	// get a assigned code of switch_num.
	uint16_t hidcode = read_nvm_code(switch_num - 1, current_layer);
	// 
	if (hidcode != 0) {
		uint8_t code = (uint8_t)hidcode & 0xff;
		uint8_t mod = (hidcode >> 8) & 0xff; 
		if ((code == HID_X_FN1) && state) {	// layer switch key. this is not sent to host, but used for layer switching.
			current_layer ^= 1;
			return;
		}
		if (IS_MACRO_KEYCODE(code)) {
			if (state) {
				active_macro = hidcode - MACRO_KEYCODE_BASE;
				if (macro_ptrs[active_macro] == 0) {	// no macro code.
					active_macro = 0;
					return;
				}
				active_macro++;
				macro_index = 0;
				macro_delay_count = 0;
			}
		} else {
			if (!state)
				send_key(code, 0);
			if (mod) {
				send_modifiers(mod, state);
				delay(20);
			}
			if (state)
			send_key(code, 1);
		}
	}
}

static uint8_t last_stable = 0;
static uint8_t prev_states = 0;
void scan() {
	__data uint8_t switch_states = 0;
	for(uint8_t row = 0; row < sizeof(rows); row++) {
		P1 &= ~row_masks[row];		// select a row.
		delayMicroseconds(25);
		switch_states |= ((~P3 & 3) << (row << 1));
		P1 |= row_masks[row];	
		delayMicroseconds(25);
	}
	// check if current result and previous result is match.
	bool f = (prev_states != switch_states);
	prev_states = switch_states;
	if (f) 	return;	// no match. may be bounced.

	uint8_t changes = switch_states ^ last_stable;
	last_stable = switch_states;
	if (changes) {
		uint8_t mask = 1;
		for (uint8_t i = 0; i < 8; i++, mask <<=1 )	
			if (changes & mask) {	// check if switch states are changed or not.
				uint8_t sw = i + 1;
				key_event(sw, (switch_states & mask) ? 1 : 0);	
			}
	}
}

// boot loader entry address is defined in ch5xx.h
void enter_bootloader_mode() {
#if defined(BOOT_LOAD_ADDR)
	led_off();
	USB_CTRL = 0;
	EA = 0; // Disabling all interrupts is required.
	TMOD = 0;
	delay(10);
	__asm__("lcall #0x3800"); // Jump to bootloader code
	for(;;) {}
#endif
}

// type_macro_strings() is called repeatedly from loop() by 10msec.  
// When a modifier keycode appears in the macro, send the corresponding modifier-on event.
// When the macro reaches its end, if any modifiers were turned on, send modifier-off events for all of them.
// Modifier-off events at the end are sent regardless of the physical modifier state.
void type_macro_strings() {
	static uint8_t mod = 0;
	static uint8_t seg_start_index = 0xff;	// this is used for tracking the start index of a segment when processing segment start and goto codes in macro. 0xff means no segment start encountered yet.	

	if (macro_delay_count > 0) {
		macro_delay_count--;
		return ;
	}

	if (macro_index == 0)
		seg_start_index = 0xff;

	uint16_t macro_base = macro_ptrs[active_macro - 1];
	if (macro_base == 0) {	// no macro code.
		active_macro = 0;
		macro_delay_count = 0;
		seg_start_index = 0xff;
		return ;
	}
	uint8_t code = eeprom_read_byte(macro_base + macro_index);
	if (code == 0) {	// end of macro code.
		active_macro = 0;
		macro_index = 0;
		macro_delay_count = 0;
		mod = 0;
		seg_start_index = 0xff;
		kbd_releaseAll();
		return ;
	}

	if (code == HID_M_SEGSTART) {
		if (seg_start_index == 0xff) {
			seg_start_index = macro_index;
		}
		macro_index++;
		return ;
	}

	if (code == HID_M_GOTO_SEG) {
		macro_index = (seg_start_index == 0xff) ? 0 : seg_start_index;
		return ;
	}

	if (IS_MACRO_DELAY_CODE(code)) {
		switch (code) {
		case HID_M_DELAY100:
			macro_delay_count = 10;	// set delay count for 100ms.
			break;
		case HID_M_DELAY500:
			macro_delay_count = 50;	// set delay count for 500ms.
			break;
		case HID_M_DELAY1000:
			macro_delay_count = 100;	// set delay count for 1000ms.
			break;
		default:
			macro_delay_count = 0;
		}
		macro_index++;
		return ;
	}

	if (IS_MODIFIER_KEYCODE(code)) { 
		mod |= (1 << ((code - HID_MODIFIERS) & 0x7));	// 0～7 for left mods.
		if ((mod & modifiers) & mod) {	// if some modifiers are already on, send the new modifiers state.	
			send_modifiers(mod, false);
		} else {
			send_modifiers(mod, true);
		}
		delay(20);
	} else {
		send_key(code, 1);
		delay(10);
		send_key(code, 0);
	}
		macro_index++;
	return ;
}

void keyscan() {
	static unsigned long last_time = 0;
	if (!should_run_periodic(&last_time, 20))
		return;
	if (active_macro)
		type_macro_strings();
	scan();
	// ついでにLEDも更新。レイヤー0のときは消灯、レイヤー1のときは点灯。
	digitalWrite(KB_LED_PIN, current_layer == 0 ? KB_LED_OFF : KB_LED_ON);
}


// 所定の時間が経過したら暗くし、消灯する。
unsigned long bg_color_time = 0;
unsigned long sled_dim_time = 0;
void sled_task() {
	if (bg_color_time == 0)
		return;
	unsigned long now = millis();
	if (now - bg_color_time < 1000)
		return;
	// 1秒経過後、50msごとに段階的に暗くする。
	if (sled_dim_time == 0 || now - sled_dim_time >= 50) {
		sled_dim();
		sled_dim_time = now;
		if (get_sled_value() < 1) {
			sled_off();
			bg_color_time = 0;
			sled_dim_time = 0;
		}
	}
}

// Rotate color wheel
// turn off bg-leds after 10 seconds of lighting. 
#define DIR_CW	0
#define DIR_CCW	1

// bg_color() is called from encoder_task() when the encoder is turned, 
//  and also can be called with extra=true to trigger bg color change regardless of encoder rotation.
void bg_color(uint8_t dir, bool extra) {
	static int16_t hue = 0;	
	bg_color_time = millis();
	sled_dim_time = 0;
	if (extra)
		dir = DIR_CW;
	if (dir == DIR_CW)
		hue = hue + 2;
	else 
		hue = hue - 2;
	if (hue < 0)
		hue = 359;
	else if (hue > 359)
		hue = 0;	
	hue_to_led(hue);
}

#include "r_encoder.h"
void encoder_task() {
	static int16_t last_counter = 0;
	static unsigned long last_time = 0;
	if (!should_run_periodic(&last_time, 2))
		return;
	int16_t delta = get_encoder_count() - last_counter;
	if (delta == 0)
		return;
	uint8_t dir = delta < 0 ? DIR_CCW : DIR_CW;
	uint16_t code = get_re_keycode(0, current_layer, dir);
	put_key_send_queue(code, 1);
	put_key_send_queue(code, 0);
	last_counter = get_encoder_count();
	bg_color(dir, false);
} 

// Clarity is important
void setup() {
	usbhid_init();
	pinMode(KB_LED_PIN, OUTPUT);
	serial_led_init();
	led_off();
	encoder_init();

	for(uint8_t i = 0; i < sizeof(cols); i++)
		pinMode(cols[i], INPUT_PULLUP);
	for(uint8_t i = 0; i < sizeof(rows); i++) {
		pinMode(rows[i], OUTPUT);
		digitalWrite(rows[i], 1);
	}
	init_nvm_keymap();
	wdt_enable(WDT_TIMEOUT);
}

void loop() {
	wdt_update();
	keyscan();
	encoder_task();
	process_send_key_queue();
	sled_task();
	delay(2);
}

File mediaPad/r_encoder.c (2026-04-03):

/**
 * r_encoder.c get encoder counts and dir of rotation.
 * Copyright (c) 2024 Takeshi Higasa, okiraku-camera.tokyo
 * 
 * This software is released under the MIT License.
 * http://opensource.org/licenses/mit-license.php
 * 
 */

#include "r_encoder.h"
#define ENC_A	33
#define ENC_B	34
static int16_t enc_counter = 0;
static int8_t prevEncoderState = 0;

void encoder_init() {
  pinMode(ENC_A, INPUT_PULLUP);
  pinMode(ENC_B, INPUT_PULLUP);
	enc_counter = 0;
	prevEncoderState = 0;
}

int16_t get_encoder_count() {
	int8_t encoderState = digitalRead(ENC_A) | (digitalRead(ENC_B) << 1);
	int8_t stateChange = encoderState - prevEncoderState;
	if (encoderState == 2) {
		if (stateChange == 2)
			enc_counter--;
		else if (stateChange == -1)
			enc_counter++;
	}
	prevEncoderState = encoderState;
	return enc_counter;
}

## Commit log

2026-04-04 change some keycodes. Add macro repeat codes, bug fix for modifier keys.
    [mediaPad.ino]
2026-04-06 change encoder timing.
2026-04-11 Add READMEs for PCB.
